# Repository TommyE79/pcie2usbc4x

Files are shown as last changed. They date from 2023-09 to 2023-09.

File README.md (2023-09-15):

# PCIe x4 to USB-C Adaptoid

A PCIe to USB-C adapter board -- plugs into a PCIe 4x card slot to breakout the data and clock lanes to a USB-C connector. 
Includes AC coupling caps and jumper resistors to aid in debugging/hacking.
Tested up to PCIe Gen 2 at 5.0 Gbps (though threre's plenty of room for improving the signal integrity).

[x] in 2nd step updating to PCIe 3.0 Standart

### Schematic

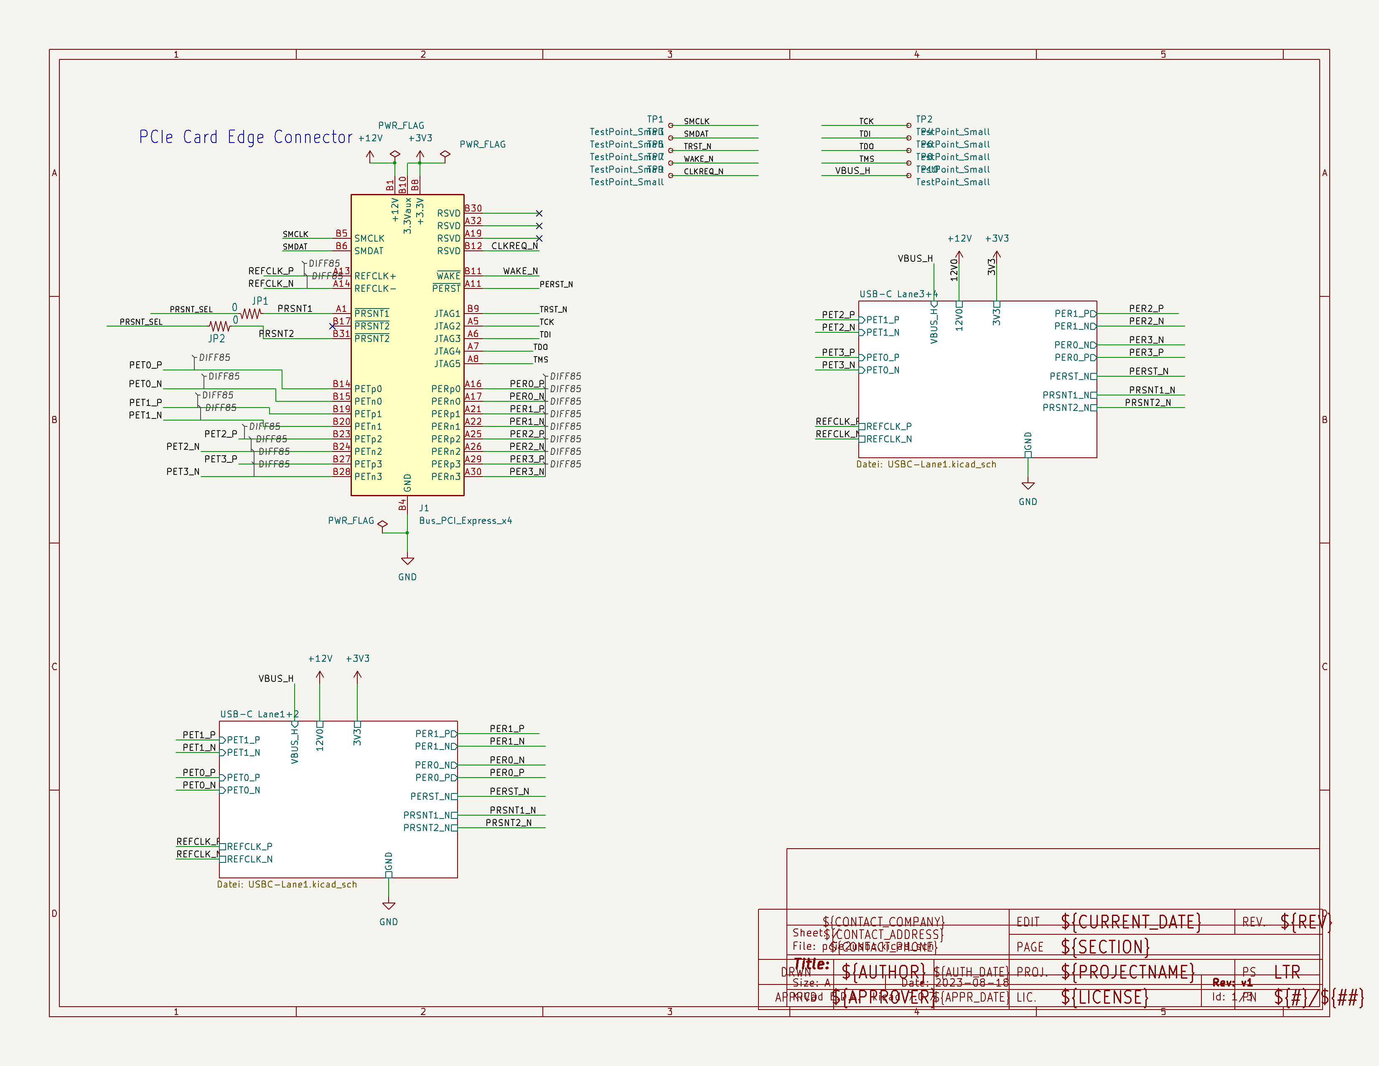
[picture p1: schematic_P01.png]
Schematic page 1
#### 
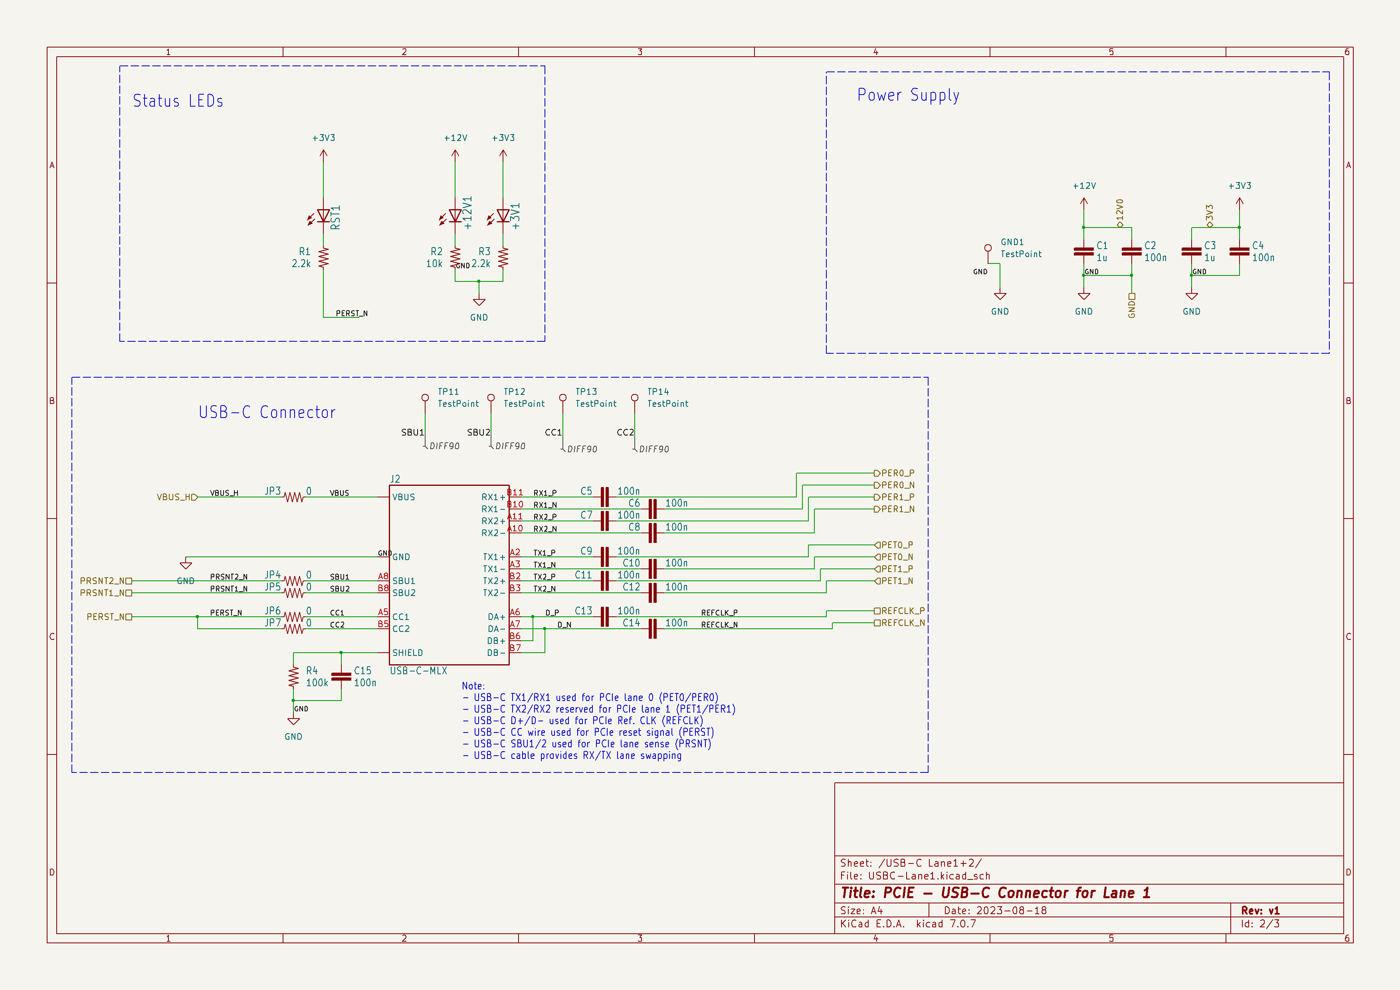
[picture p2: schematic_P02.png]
Schematic page 2
#### 
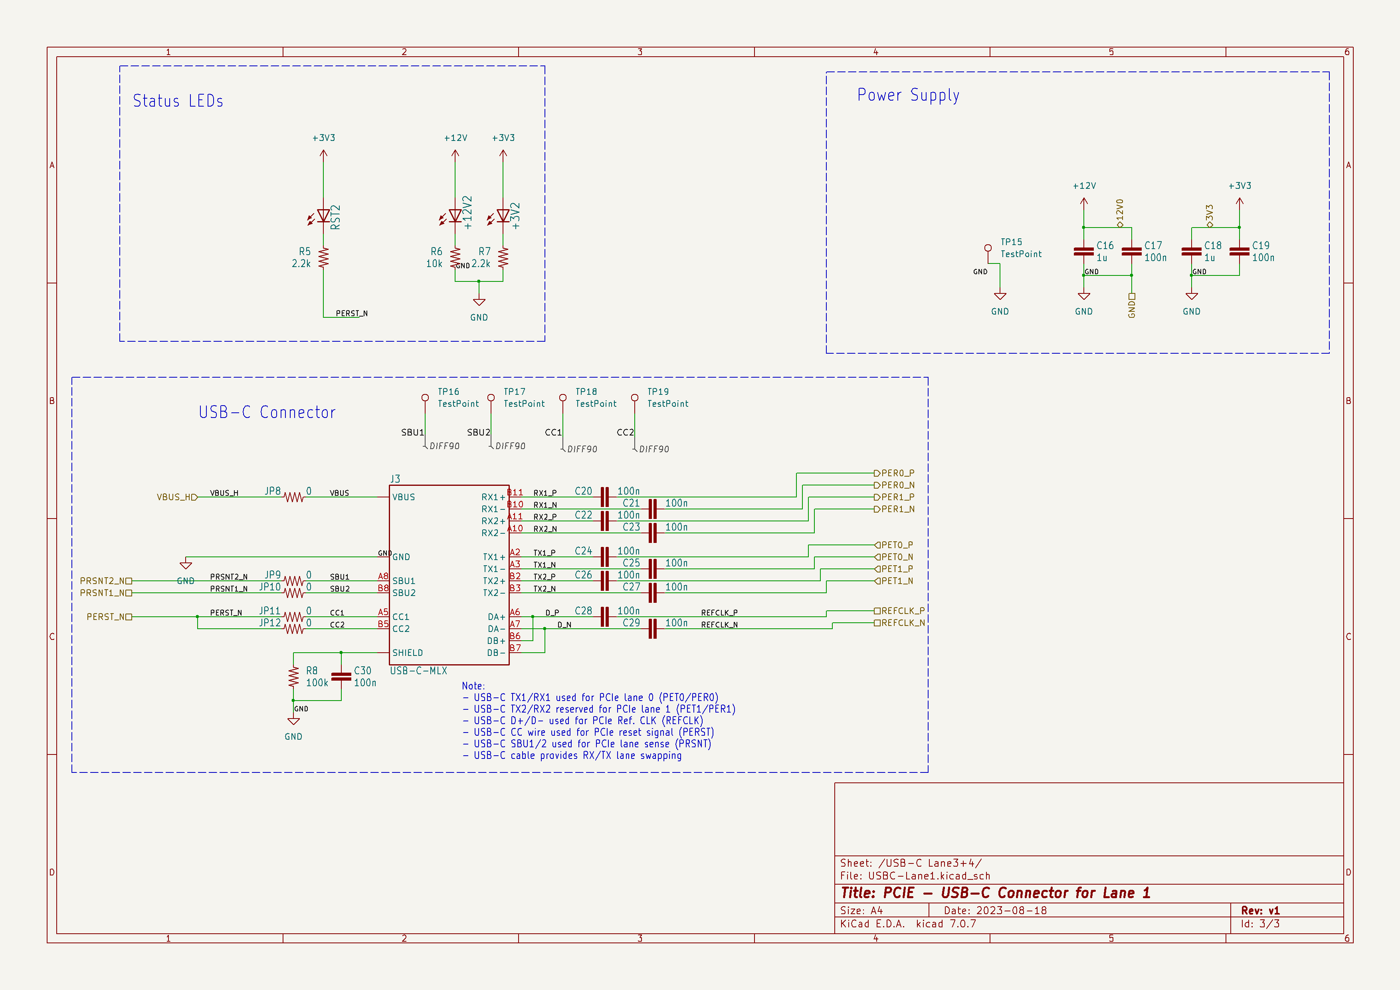
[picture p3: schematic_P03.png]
Schematic page 3
#### 

### PCB Bottom Side

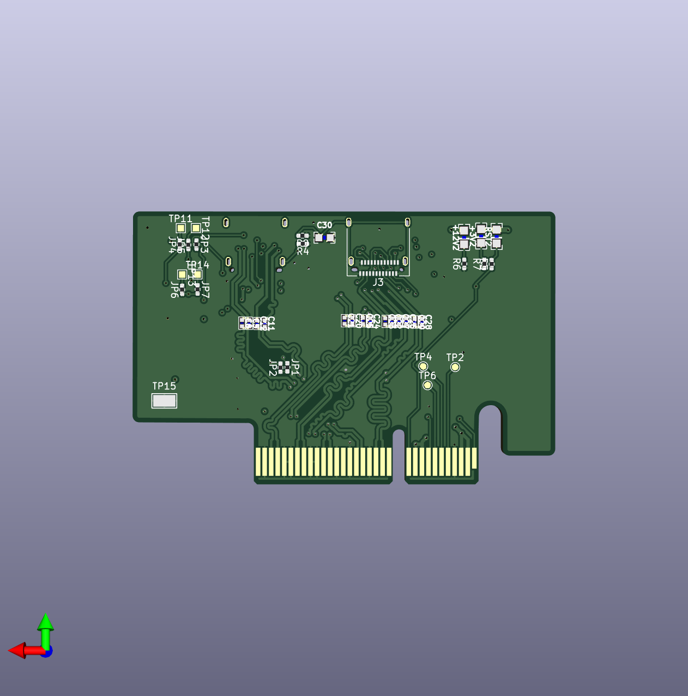
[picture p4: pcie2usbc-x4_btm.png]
Bottom Side
#### 

### PCB Top Side

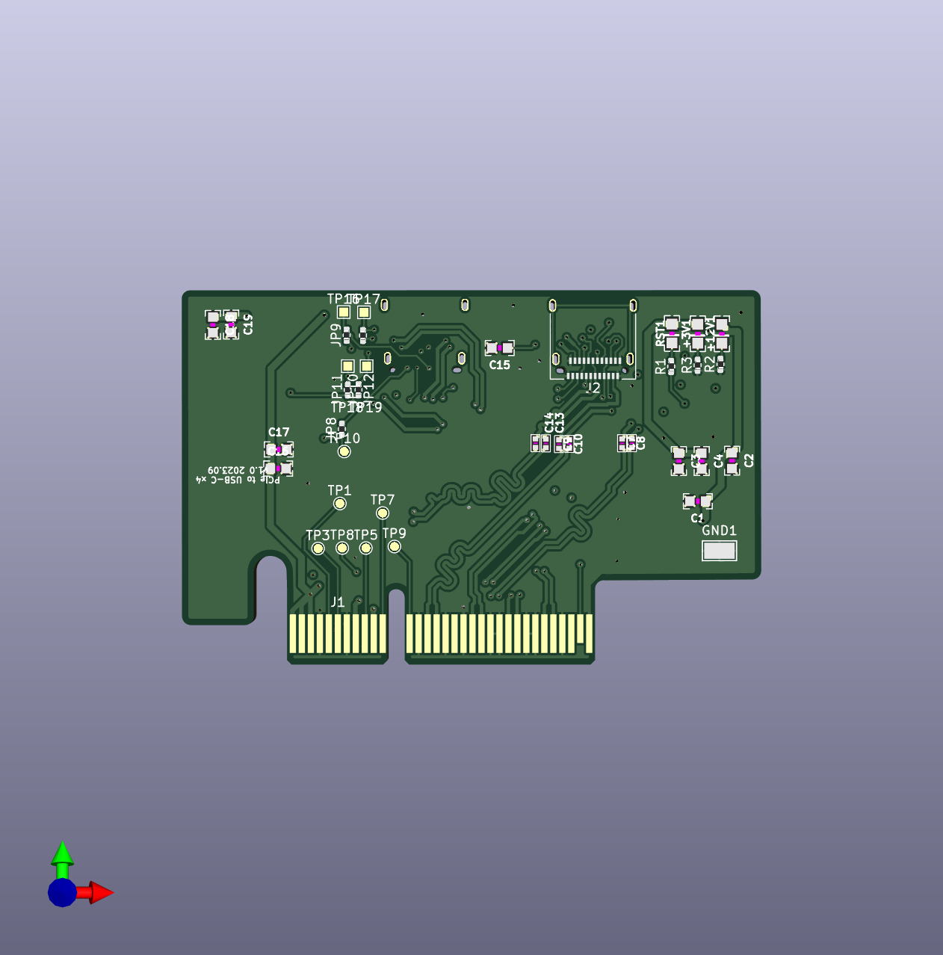
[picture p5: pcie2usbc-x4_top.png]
Top Side
####

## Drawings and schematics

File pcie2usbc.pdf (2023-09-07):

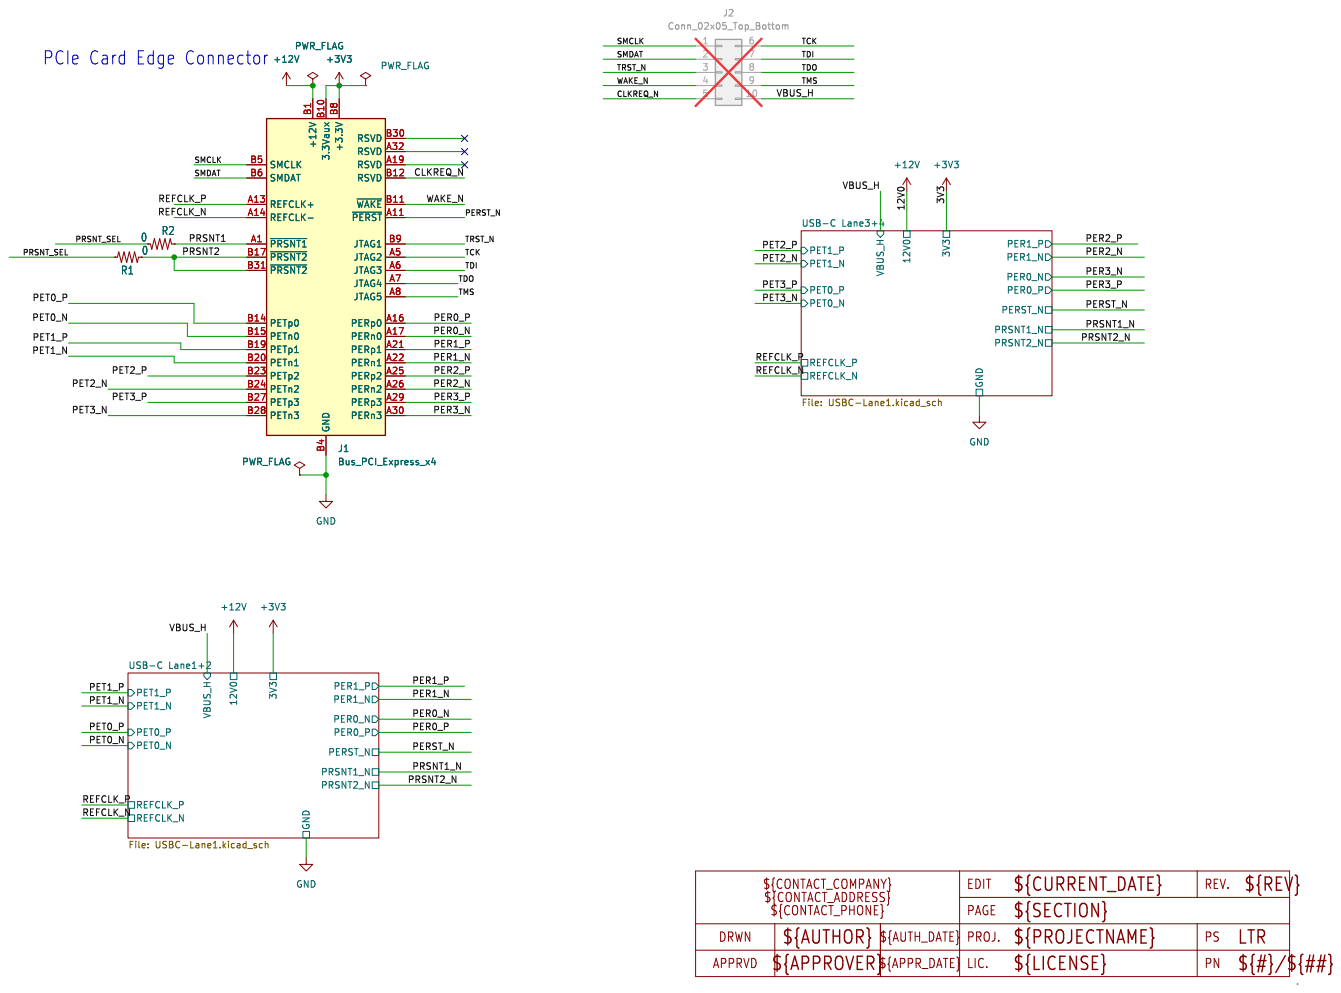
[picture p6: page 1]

${CONTACT_COMPANY} ${CONTACT_ADDRESS}

${AUTHOR} | ${AUTH_DATE}

APPRVD

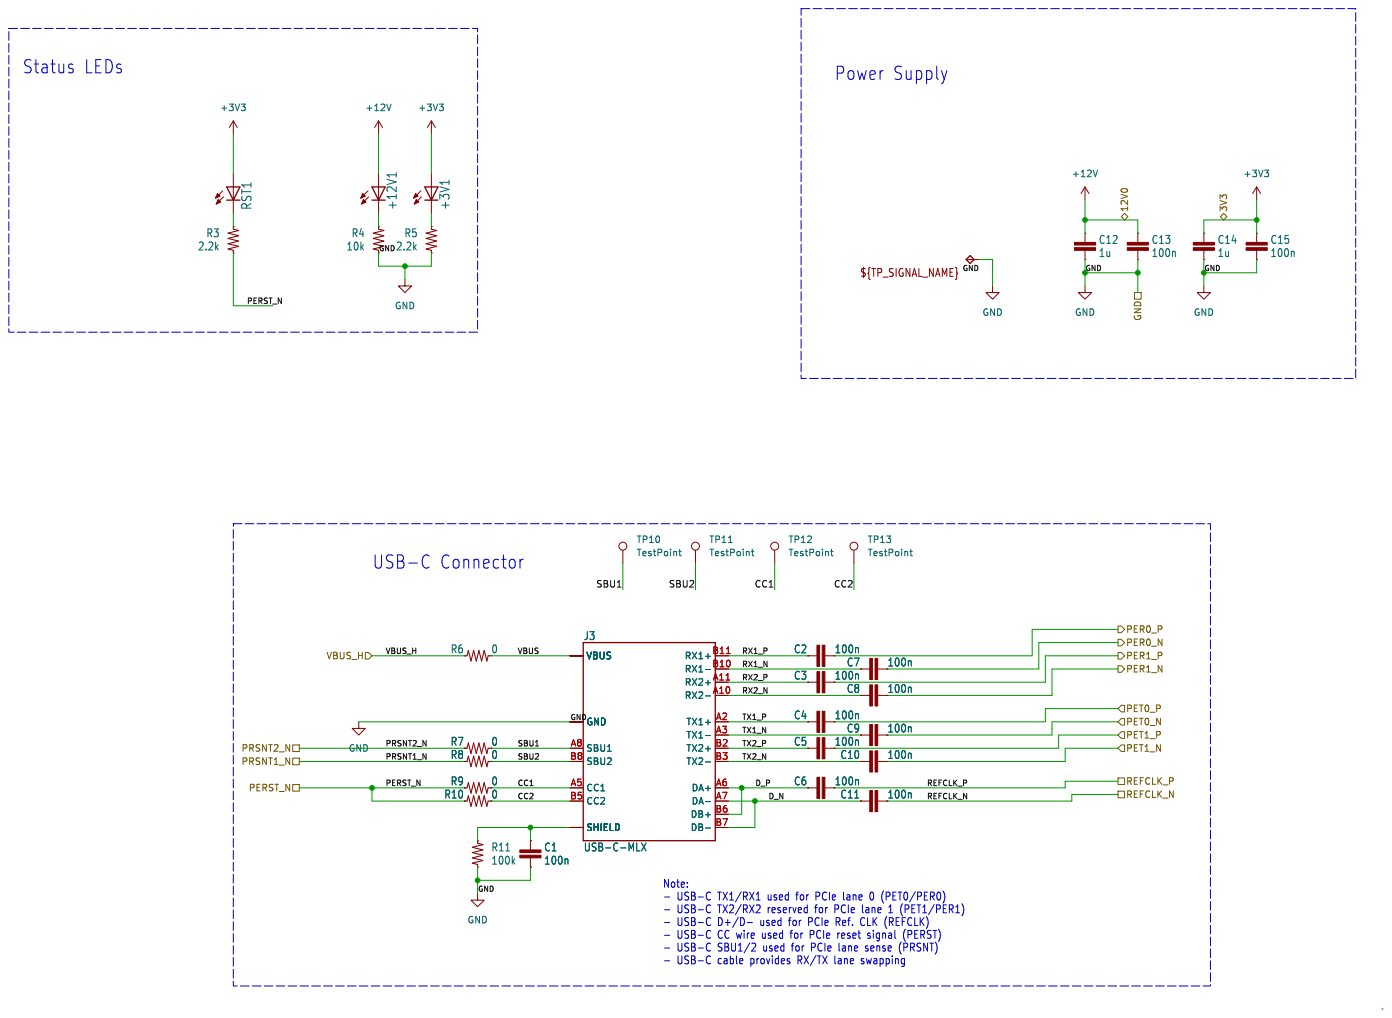
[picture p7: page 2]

Power Supply Status LEDs

- USB-C TX2/RX2 reserved for PCIe lane 1 (PET1/PER1)
- USB-C CC wire used for PCIe reset signal (PERST)
- USB-C SBU1/2 used for PCIe lane sense (PRSNT)
- USB-C cable provides RX/TX lane swapping

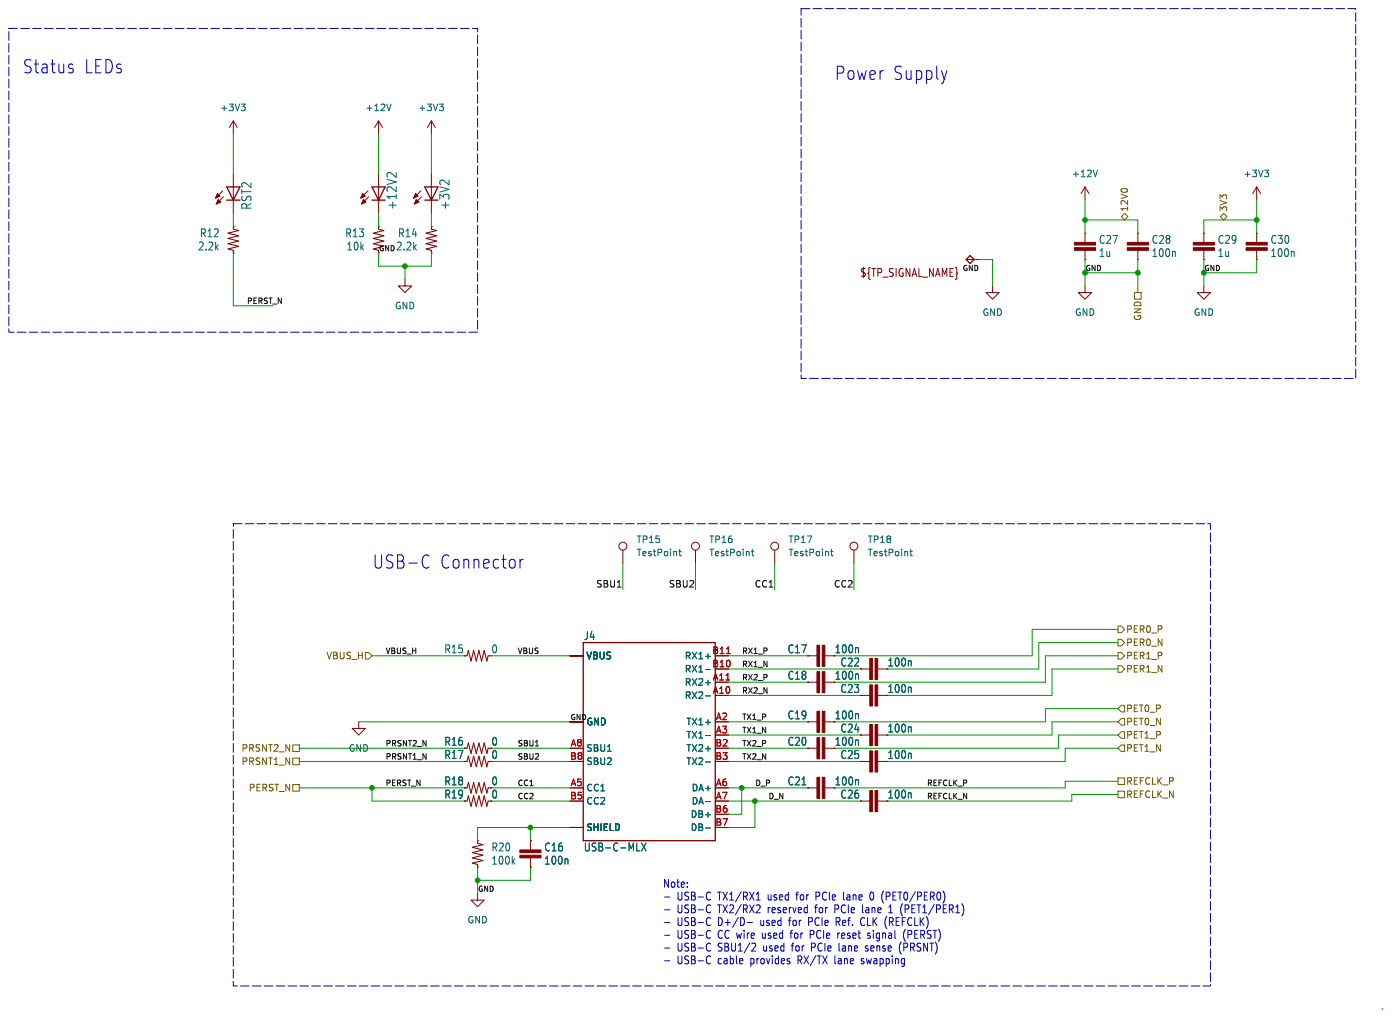
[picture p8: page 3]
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

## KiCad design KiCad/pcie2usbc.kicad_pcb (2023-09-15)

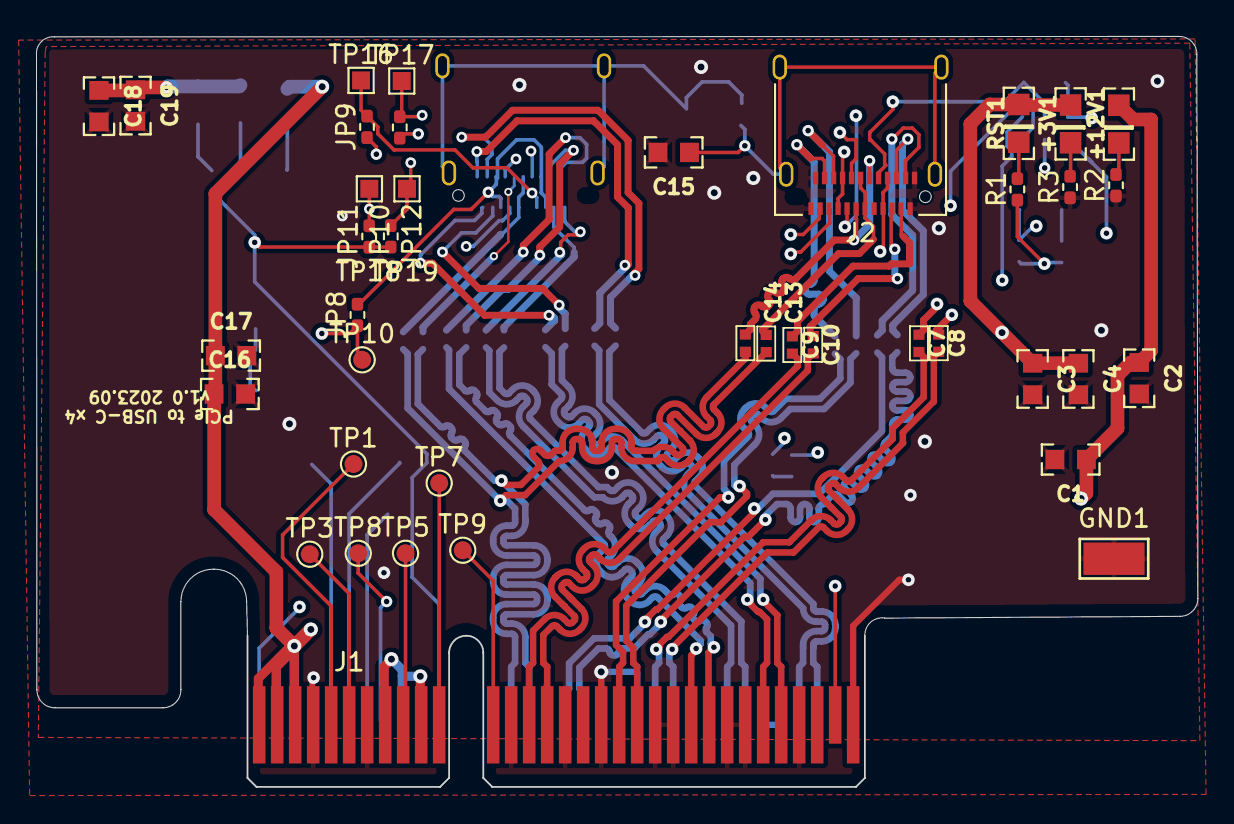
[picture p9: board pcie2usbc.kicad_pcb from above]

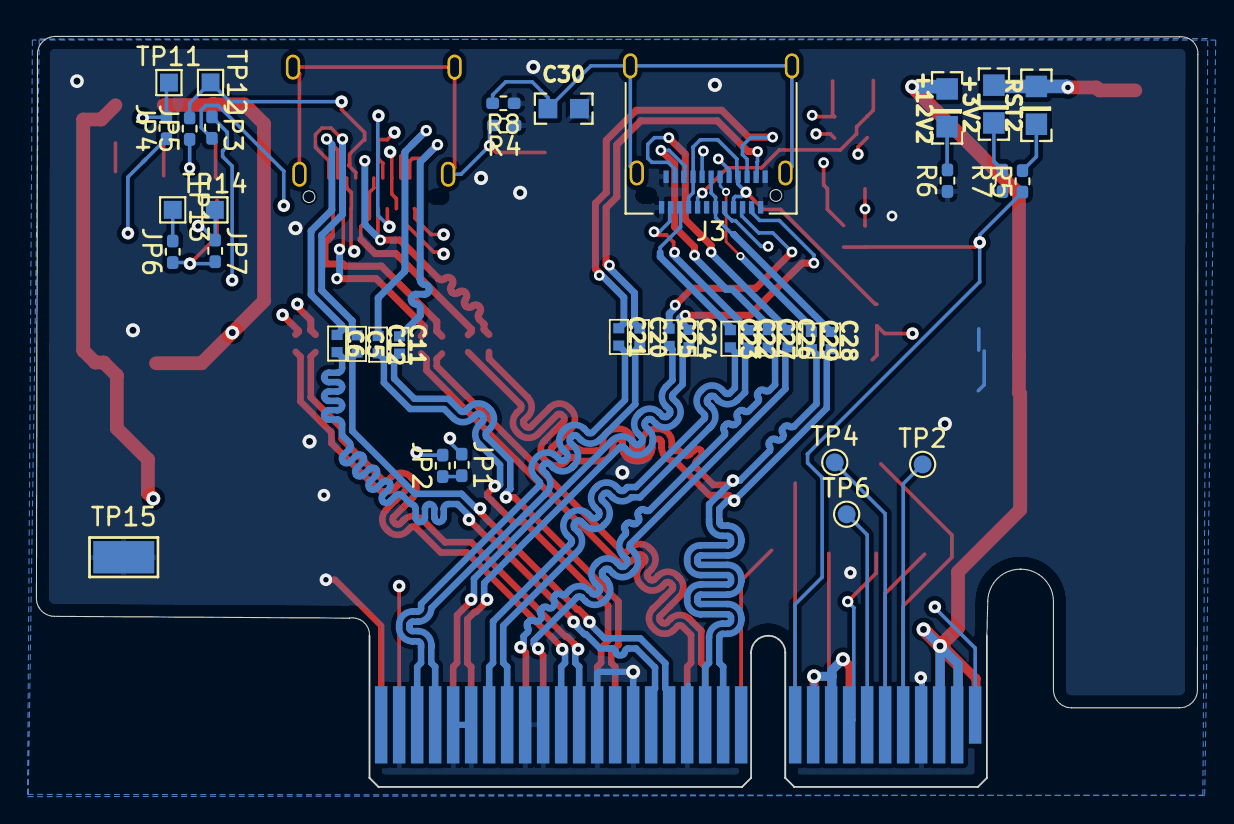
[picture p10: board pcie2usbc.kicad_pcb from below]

Board: 4 copper layers, 64.5 x 41.7 mm, 79 parts (39 on the bottom side), 72 nets.

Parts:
+3V1, +3V2, +12V1, +12V2: LEDSML0805; SML0805
C1, C3, C16, C18: 1u; C0603K
C2, C4, C15, C17, C19, C30: 100n; C0603K
C5, C6, C7, C8, C9, C10, C11, C12, C13, C14, C20, C21, C22, C23, C24, C25, C26, C27, C28, C29: 100n; C0402
GND1: TestPoint; TestPoint_Keystone_5015_Micro-Minature
J1: Bus_PCI_Express_x4; BUS_PCIexpress_x4
J2, J3: USB-C-MLX; USB_C_Receptacle_Amphenol_12401610E4-2A
JP1, JP2, JP3, JP4, JP5, JP6, JP7, JP8, JP9, JP10, JP11, JP12: 0; R_0402_1005Metric_Pad0.72x0.64mm_HandSolder
R1, R3, R5, R7: 2.2k; R_0402_1005Metric_Pad0.72x0.64mm_HandSolder
R2, R6: 10k; R_0402_1005Metric_Pad0.72x0.64mm_HandSolder
R4, R8: 100k; R_0402_1005Metric_Pad0.72x0.64mm_HandSolder
RST1, RST2: LEDSML0805; SML0805
TP1, TP2, TP3, TP4, TP5, TP6, TP7, TP8, TP9, TP10: TestPoint_Small; TestPoint_Pad_D1.0mm
TP11, TP12, TP13, TP14, TP16, TP17, TP18, TP19: TestPoint; TestPoint_Pad_1.0x1.0mm
TP15: TestPoint; TestPoint_Keystone_5015_Micro-Minature

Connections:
+3V3: +3V1.A, +3V2.A, C3.1, C4.1, C18.1, C19.1, J1.A9 (+3.3V), J1.A10 (+3.3V), J1.B8 (+3.3V), J1.B10 (3.3Vaux), RST1.A, RST2.A
+12V: +12V1.A, +12V2.A, C1.1, C2.1, C16.1, C17.1, J1.A2 (+12V), J1.A3 (+12V), J1.B1 (+12V), J1.B2 (+12V), J1.B3 (+12V)
/CLKREQ_N: J1.B12 (RSVD), TP9.1
/PER0_N: C6.2, J1.A17 (PERn0)
/PER0_P: C5.2, J1.A16 (PERp0)
/PER1_N: C8.2, J1.A22 (PERn1)
/PER1_P: C7.2, J1.A21 (PERp1)
/PER2_N: C23.2, J1.A26 (PERn2)
/PER2_P: C22.2, J1.A25 (PERp2)
/PER3_N: C21.2, J1.A30 (PERn3)
/PER3_P: C20.2, J1.A29 (PERp3)
/PERST_N: J1.A11 (~PERST), J2.A8 (SBU1), JP3.1, JP4.2, JP5.1, JP6.1, JP7.2, JP8.1, JP10.1, JP11.1, JP12.2, R1.1, R5.1, TP10.1, TP11.1
/PET0_N: C10.2, J1.B15 (PETn0)
/PET0_P: C9.2, J1.B14 (PETp0)
/PET1_N: C12.2, J1.B20 (PETn1)
/PET1_P: C11.2, J1.B19 (PETp1)
/PET2_N: C27.2, J1.B24 (PETn2)
/PET2_P: C26.2, J1.B23 (PETp2)
/PET3_N: C25.2, J1.B28 (PETn3)
/PET3_P: C24.2, J1.B27 (PETp3)
/PRSNT1: J1.A1 (~PRSNT1), JP1.1
/PRSNT2: J1.B31 (~PRSNT2), JP2.2
/PRSNT2_N: JP4.1, JP9.1
/PRSNT_SEL: JP1.2, JP2.1
/REFCLK_N: C14.2, C29.2, J1.A14 (REFCLK-)
/REFCLK_P: C13.2, C28.2, J1.A13 (REFCLK+)
/SMCLK: J1.B5 (SMCLK), TP1.1
/SMDAT: J1.B6 (SMDAT), TP3.1
/TCK: J1.A5 (JTAG2), TP2.1
/TDI: J1.A6 (JTAG3), TP4.1
/TDO: J1.A7 (JTAG4), TP6.1
/TMS: J1.A8 (JTAG5), TP8.1
/TRST_N: J1.B9 (JTAG1), TP5.1
/USB-C Lane1+2/CC1: J2.A5 (CC1), JP6.2, TP13.1
/USB-C Lane1+2/CC2: J2.B5 (CC2), JP7.1, TP14.1
/USB-C Lane1+2/D_N: C14.1, J2.A7 (DA-), J2.B7 (DB-)
/USB-C Lane1+2/D_P: C13.1, J2.A6 (DA+), J2.B6 (DB+)
/USB-C Lane1+2/RX1_N: C6.1, J2.B10 (RX1-)
/USB-C Lane1+2/RX1_P: C5.1, J2.B11 (RX1+)
/USB-C Lane1+2/RX2_N: C8.1, J2.A10 (RX2-)
/USB-C Lane1+2/RX2_P: C7.1, J2.A11 (RX2+)
/USB-C Lane1+2/SBU2: J2.B8 (SBU2), JP5.2, TP12.1
/USB-C Lane1+2/TX1_N: C10.1, J2.A3 (TX1-)
/USB-C Lane1+2/TX1_P: C9.1, J2.A2 (TX1+)
/USB-C Lane1+2/TX2_N: C12.1, J2.B3 (TX2-)
/USB-C Lane1+2/TX2_P: C11.1, J2.B2 (TX2+)
/USB-C Lane1+2/VBUS: J2.A4 (VBUS), J2.A9 (VBUS), J2.B4 (VBUS), J2.B9 (VBUS), JP3.2
/USB-C Lane3+4/CC1: J3.A5 (CC1), JP11.2, TP18.1
/USB-C Lane3+4/CC2: J3.B5 (CC2), JP12.1, TP19.1
/USB-C Lane3+4/D_N: C29.1, J3.A7 (DA-), J3.B7 (DB-)
/USB-C Lane3+4/D_P: C28.1, J3.A6 (DA+), J3.B6 (DB+)
/USB-C Lane3+4/RX1_N: C21.1, J3.B10 (RX1-)
/USB-C Lane3+4/RX1_P: C20.1, J3.B11 (RX1+)
/USB-C Lane3+4/RX2_N: C23.1, J3.A10 (RX2-)
/USB-C Lane3+4/RX2_P: C22.1, J3.A11 (RX2+)
/USB-C Lane3+4/SBU1: J3.A8 (SBU1), JP9.2, TP16.1
/USB-C Lane3+4/SBU2: J3.B8 (SBU2), JP10.2, TP17.1
/USB-C Lane3+4/TX1_N: C25.1, J3.A3 (TX1-)
/USB-C Lane3+4/TX1_P: C24.1, J3.A2 (TX1+)
/USB-C Lane3+4/TX2_N: C27.1, J3.B3 (TX2-)
/USB-C Lane3+4/TX2_P: C26.1, J3.B2 (TX2+)
/USB-C Lane3+4/VBUS: J3.A4 (VBUS), J3.A9 (VBUS), J3.B4 (VBUS), J3.B9 (VBUS), JP8.2
/WAKE_N: J1.B11 (~WAKE), TP7.1
GND: C1.2, C2.2, C3.2, C4.2, C15.2, C16.2, C17.2, C18.2, C19.2, C30.2, GND1.1, J1.A4 (GND), J1.A12 (GND), J1.A15 (GND), J1.A18 (GND), J1.A20 (GND), J1.A23 (GND), J1.A24 (GND), J1.A27 (GND), J1.A28 (GND), J1.A31 (GND), J1.B4 (GND), J1.B7 (GND), J1.B13 (GND), J1.B16 (GND), J1.B18 (GND), J1.B21 (GND), J1.B22 (GND), J1.B25 (GND), J1.B26 (GND), J1.B29 (GND), J1.B32 (GND), J2.A1 (GND), J2.A12 (GND), J2.B1 (GND), J2.B12 (GND), J3.A1 (GND), J3.A12 (GND), J3.B1 (GND), J3.B12 (GND), R2.1, R3.1, R4.1, R6.1, R7.1, R8.1, TP15.1
unnamed: +3V1.C, R3.2
unnamed: +3V2.C, R7.2
unnamed: +12V1.C, R2.2
unnamed: +12V2.C, R6.2
unnamed: C15.1, J2.S1 (SHIELD), R4.2
unnamed: C30.1, J3.S1 (SHIELD), R8.2
unnamed: R1.2, RST1.C
unnamed: R5.2, RST2.C

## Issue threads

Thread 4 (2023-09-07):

Create an receiver boards version

TommyE79, 2023-09-07:
- [ ] create schematics
- [ ] review
- [ ] create pcb layout
- [ ] optimize layout to use only 2 layers
- [ ] optimize layout to PCIe 3.0 specs, eg adjust diff pair impedance to 85 ohms
- [ ] review
- [ ] test

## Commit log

2023-09-06 WiP layout
    [USBC-Lane1.kicad_sch, pcie2usbc.kicad_pcb, pcie2usbc.kicad_sch]
2023-09-07 routing completed - review requested
    [pcie2usbc.kicad_pcb]
2023-09-07 v1.0 final for reviwe
    [pcie2usbc.brd, pcie2usbc.kicad_pcb, pcie2usbc.sch]
2023-09-08 reviwe - impedance matching
    as the impedance network settings didn't apply correctly, layout was redone with correct impedance
    [USBC-Lane1.kicad_sch, pcie2usbc.kicad_pcb, pcie2usbc.kicad_sch]
2023-09-15 Final rework
    Layout completed finally
    [USBC-Lane1.kicad_sch, freerouting.dsn, pcie2usbc.kicad_pcb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]
2023-09-15 README.md update
    updatede readme.md
    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
    [USBC-Lane1.kicad_sch]
